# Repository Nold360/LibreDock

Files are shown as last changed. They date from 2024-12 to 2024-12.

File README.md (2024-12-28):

# LibreDock

LibreDock is a MAX4885-based VGA Docking PCB for portable devices. It allows switching VGA and up to four controller signal lines using a very small PCB.

As a docking connector it uses HDMI, which is "misused" for this purpose.

## Features & Requirements

Switching of:
  - VGA (R,G,B,H & V)
  - Player 1 Controller Data (Controller 2, 3 and 4 are only available in "docked mode")

Additional Features:
  - Charging through dock
  - Stereo Audio (L & R) to dock

Requirements:
  - 5v & 3.3v

## Front

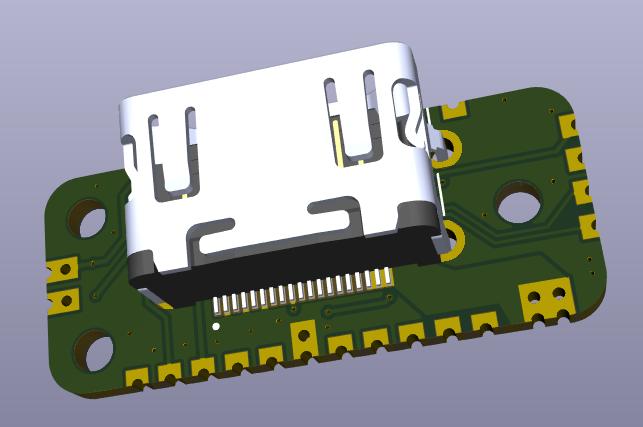
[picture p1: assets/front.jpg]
front


## Back

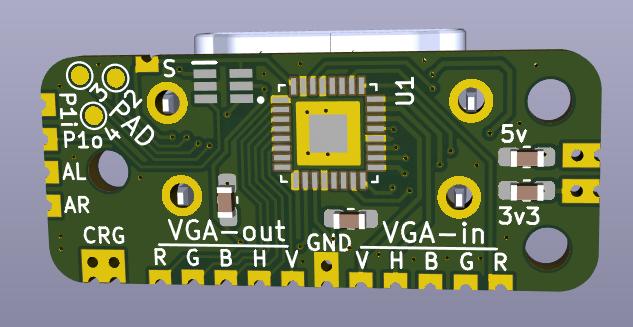
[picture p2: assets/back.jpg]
back


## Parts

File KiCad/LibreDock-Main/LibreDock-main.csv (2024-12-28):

Source: | /home/nold/Nextcloud/CAD/KiCAD/dock64/dock64.kicad_sch
Date: | Thu Oct 19 19:00:56 2023
Tool: | Eeschema 7.0.7
Generator: | /app/share/kicad/plugins/bom_csv_grouped_by_value.py
Component Count: | 32
Collated Components:
Item | Qty | Reference(s) | Value | LibPart | Footprint | Datasheet | DNP | AVAILABILITY | Arrow Part Number | Arrow Price/Stock | Availability | Check_prices | DESCRIPTION | Description | Height | MANUFACTURER | MAXIMUM_PACKAGE_HEIGHT | MF | MP | Manufacturer_Name | Manufacturer_Part_Number | Mouser Part Number | Mouser Price/Stock | PACKAGE | PARTREV | PRICE | Package | Price | Purchase-URL | STANDARD | SnapEDA_Link
1 | 4 | C1, C2, C3, C4 | C_Small | Device:C_Small | Capacitor_SMD:C_0603_1608Metric_Pad1.08x0.95mm_HandSolder | ~
2 | 3 | H1, H2, H3 | MountingHole | Mechanical:MountingHole | MountingHole:MountingHole_2.2mm_M2 | ~
3 | 1 | IC1 | PI5A3157CEX | PI5A3157CEX:PI5A3157CEX | KiCad:SOT65P210X110-6N | https://www.diodes.com/assets/Datasheets/PI5A3157.pdf |  |  | PI5A3157CEX | https://www.arrow.com/en/products/pi5a3157cex/diodes-incorporated |  |  |  |  | 1.1 |  |  |  |  | Diodes Inc. | PI5A3157CEX | 729-PI5A3157CEX | https://www.mouser.co.uk/ProductDetail/Diodes-Incorporated/PI5A3157CEX?qs=hFKXOjF5MkYOFZffF%2FEnpw%3D%3D
4 | 1 | J1 | SS-53000-001 | SS-53000-001:SS-53000-001 | symbols-footprints:STEWART_SS-53000-001 |  |  |  |  |  | In Stock | https://www.snapeda.com/parts/SS-53000-001/Stewart+Connector/view-part/?ref=eda |  | HDMI Connector | Right Angle | Without Flange | -20C to 85C |  | BelFuse | 6.18 mm | Stewart Connector | SS-53000-001 |  |  |  |  |  | A0 |  | None | None | https://www.snapeda.com/api/url_track_click_mouser/?unipart_id=4628816&manufacturer=Stewart Connector&part_name=SS-53000-001&search_term=hdmi connector | Manufacturer Recommendations | https://www.snapeda.com/parts/SS-53000-001/Stewart+Connector/view-part/?ref=snap
5 | 1 | TP1 | Bo | Connector:TestPoint | symbols-footprints:CasPowerPad 1x1 | ~
6 | 1 | TP2 | Go | Connector:TestPoint | symbols-footprints:CasPowerPad 1x1 | ~
7 | 1 | TP3 | Ro | Connector:TestPoint | symbols-footprints:CasPowerPad 1x1 | ~
8 | 1 | TP4 | Ho | Connector:TestPoint | symbols-footprints:CasPowerPad 1x1 | ~
9 | 1 | TP5 | Vo | Connector:TestPoint | symbols-footprints:CasPowerPad 1x1 | ~
10 | 1 | TP6 | Bi | Connector:TestPoint | symbols-footprints:CasPowerPad 1x1 | ~
11 | 1 | TP7 | Gi | Connector:TestPoint | symbols-footprints:CasPowerPad 1x1 | ~
12 | 1 | TP8 | Ri | Connector:TestPoint | symbols-footprints:CasPowerPad 1x1 | ~
13 | 1 | TP9 | Hi | Connector:TestPoint | symbols-footprints:CasPowerPad 1x1 | ~
14 | 1 | TP10 | Vi | Connector:TestPoint | symbols-footprints:CasPowerPad 1x1 | ~
15 | 1 | TP11 | P1i | Connector:TestPoint | symbols-footprints:CasPowerPad 1x1 | ~
16 | 1 | TP12 | P1o | Connector:TestPoint | symbols-footprints:CasPowerPad 1x1 | ~
17 | 1 | TP13 | 5v | Connector:TestPoint | symbols-footprints:CasPowerPad 2x1 | ~
18 | 1 | TP14 | 3v3 | Connector:TestPoint | nold-customs:nolds-TestPoint_Pad_D1.0mm | ~
19 | 1 | TP15 | GND | Connector:TestPoint | symbols-footprints:CasPowerPad 2x1 | ~
20 | 1 | TP16 | AL | Connector:TestPoint | symbols-footprints:CasPowerPad 1x1 | ~
21 | 1 | TP17 | AR | Connector:TestPoint | symbols-footprints:CasPowerPad 1x1 | ~
22 | 1 | TP18 | SENSE | Connector:TestPoint | symbols-footprints:CasPowerPad 1x1 | ~
23 | 1 | TP19 | P2 | Connector:TestPoint | nold-customs:nolds-TestPoint_Pad_D1.0mm | ~
24 | 1 | TP20 | P3 | Connector:TestPoint | nold-customs:nolds-TestPoint_Pad_D1.0mm | ~
25 | 1 | TP21 | P4 | Connector:TestPoint | nold-customs:nolds-TestPoint_Pad_D1.0mm | ~
26 | 1 | TP22 | CRG | Connector:TestPoint | symbols-footprints:CasPowerPad 2x2 | ~
27 | 1 | U1 | MAX4885ETJ_ | MAX4885ETJ_:MAX4885ETJ_ | symbols-footprints:QFN50P500X500X80-33N |  |  | Unavailable |  |  | In Stock | https://www.snapeda.com/parts/MAX4885ETJ+/Maxim+Integrated/view-part/?ref=eda | Complete VGA Multiplexer 32-Pin TQFN EP | Analog Switch/Analog Multiplexer Seven 2:1 32-Pin TQFN EP Tube |  |  |  | Maxim Integrated Products | MAX4885ETJ+ |  |  |  |  | TQFN-32 Maxim |  | None | None | None |  |  | https://www.snapeda.com/parts/MAX4885ETJ+/Maxim+Integrated/view-part/?ref=snap

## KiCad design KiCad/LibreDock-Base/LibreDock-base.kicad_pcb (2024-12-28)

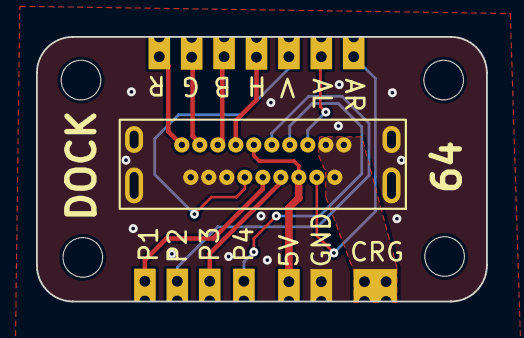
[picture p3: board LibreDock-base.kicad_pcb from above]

Board: 2 copper layers, 25.0 x 14.7 mm, 19 parts (0 on the bottom side), 14 nets.

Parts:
H1, H2, H3, H4: MountingHole; MountingHole_2.2mm_M2
J1: SS-53000-001; HDMI Male Type-A Elecbee
R1: G; CasPowerPad 2x1
R2: B; CasPowerPad 2x1
R3: H; CasPowerPad 2x1
R4: V; CasPowerPad 2x1
R5: P1; CasPowerPad 2x1
R6: P2; CasPowerPad 2x1
R7: P3; CasPowerPad 2x1
R8: P4; CasPowerPad 2x1
R9: AL; CasPowerPad 2x1
R10: AR; CasPowerPad 2x1
R11: GND; CasPowerPad 2x1
R12: 5V; CasPowerPad 2x1
R13: R; CasPowerPad 2x1
U1: CRG; CasPowerPad 2x2

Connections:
5v: J1.9, J1.14, R12.1
AL: J1.15, R9.1
AR: J1.16, R10.1
B: J1.5, R2.1
C1: J1.10, R5.1
C2: J1.11, R6.1
C3: J1.12, R7.1
C4: J1.13, R8.1
CHARGE: J1.17, J1.18, J1.19, U1.1 (Vout)
G: J1.3, R1.1
GND: J1.2, J1.4, J1.6, J1.S1 (SHIELD), J1.S2 (SHIELD), J1.S3 (SHIELD), J1.S4 (SHIELD), R11.1
H: J1.7, R3.1
R: J1.1, R13.1
V: J1.8, R4.1

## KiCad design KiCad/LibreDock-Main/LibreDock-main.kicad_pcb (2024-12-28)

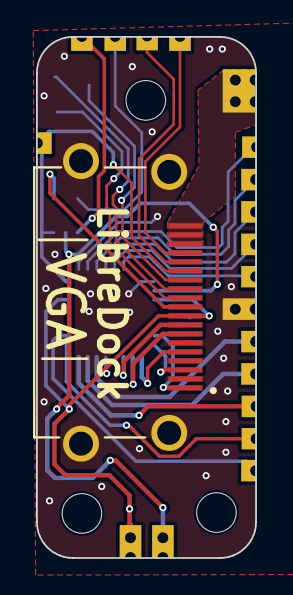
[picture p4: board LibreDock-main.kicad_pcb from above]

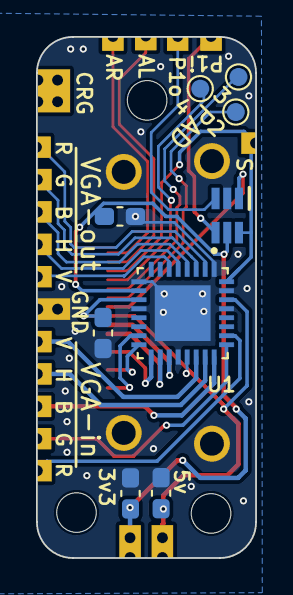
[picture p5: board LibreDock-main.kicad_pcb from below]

Board: 2 copper layers, 12.2 x 29.0 mm, 32 parts (24 on the bottom side), 28 nets.

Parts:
C1, C2, C3, C4: C_Small; C_0603_1608Metric_Pad1.08x0.95mm_HandSolder
H1, H2, H3: MountingHole; MountingHole_2.2mm_M2
IC1: PI5A3157CEX; SOT65P210X110-6N
J1: SS-53000-001; STEWART_SS-53000-001
TP1, TP6: B; CasPowerPad 1x1
TP2, TP7: G; CasPowerPad 1x1
TP3, TP8: R; CasPowerPad 1x1
TP4, TP9: H; CasPowerPad 1x1
TP5, TP10: V; CasPowerPad 1x1
TP11: P1i; CasPowerPad 1x1
TP12: P1o; CasPowerPad 1x1
TP13: 5v; CasPowerPad 2x1
TP14: 3v3; CasPowerPad 2x1
TP15: GND; CasPowerPad 2x1
TP16: AL; CasPowerPad 1x1
TP17: AR; CasPowerPad 1x1
TP18: S; CasPowerPad 1x1
TP19: P2; nolds-TestPoint_Pad_D1.0mm
TP20: P3; nolds-TestPoint_Pad_D1.0mm
TP21: P4; nolds-TestPoint_Pad_D1.0mm
TP22: CRG; CasPowerPad 2x2
U1: MAX4885ETJ_; QFN50P500X500X80-33N

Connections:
3v3: C1.1, C2.1, IC1.5 (VCC), TP14.1, U1.10 (VCL)
5v: C3.2, C4.2, J1.9, TP13.1, U1.11 (V+), U1.21 (V+), U1.30 (V+)
AL: J1.15, TP16.1
AR: J1.16, TP17.1
B: J1.5, U1.17 (B2)
C1: IC1.1 (B1), J1.10
C2: J1.11, TP19.1
C3: J1.12, TP20.1
C4: J1.13, TP21.1
CHARGE: J1.17, J1.18, J1.19, TP22.1
G: J1.3, U1.16 (G2)
GND: C1.2, C2.2, C3.1, C4.1, IC1.2 (GND), J1.2, J1.4, J1.6, J1.S1 (SHIELD), J1.S2 (SHIELD), J1.S3 (SHIELD), J1.S4 (SHIELD), TP15.1, U1.1 (~QP), U1.9 (~EN), U1.12 (GND), U1.20 (GND), U1.29 (GND), U1.31 (M), U1.33 (EP)
H: J1.7, U1.18 (H2)
unnamed: IC1.4 (A), TP11.1
unnamed: IC1.3 (B0), TP12.1
unnamed: TP1.1, U1.4 (B0)
unnamed: TP6.1, U1.24 (B1)
unnamed: TP2.1, U1.3 (G0)
unnamed: TP7.1, U1.25 (G1)
unnamed: TP4.1, U1.5 (H0)
unnamed: TP9.1, U1.23 (H1)
unnamed: TP3.1, U1.2 (R0)
unnamed: TP8.1, U1.26 (R1)
unnamed: TP5.1, U1.6 (V0)
unnamed: TP10.1, U1.22 (V1)
R: J1.1, U1.15 (R2)
SENSE: IC1.6 (S), J1.14, TP18.1, U1.32 (SEL)
V: J1.8, U1.19 (V2)
